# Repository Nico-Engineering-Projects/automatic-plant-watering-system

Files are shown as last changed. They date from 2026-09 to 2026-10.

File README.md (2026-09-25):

# Automatic Plant Watering System

An engineering project by Nico Gerber to develop an ESP32-based system that measures soil moisture and controls a water pump.

**Status:** In progress — breadboard assembly and development planning.

## Goal

Develop the hardware and firmware step by step, verify each stage, and document the design decisions, measurements and lessons learned.

## Current progress

- Relay and pump connected on the breadboard.
- ESP32 board selection, GPIO assignment, relay behaviour and electrical connections still need to be recorded and verified.
- Firmware development and functional testing are next.
- No watering performance or reliability results have been established yet.

## Planned development phases

- [ ] Verify ESP32 upload and Serial Monitor communication.
- [ ] Verify relay control and startup state with the pump disconnected.
- [ ] Verify a deliberately triggered short pump run with automatic shutoff.
- [ ] Measure and calibrate the soil-moisture sensor.
- [ ] Implement and test automatic watering with a soak period.
- [ ] Evaluate the results and document improvements.

## Planned software tools

- Visual Studio Code
- PlatformIO IDE
- Arduino framework for ESP32
- Git and GitHub for version history

The exact ESP32 board and GPIO configuration will be documented before the first firmware is added.

## Documentation

- [Development log](docs/development-log.md)
- Circuit diagrams, component list and test results will be added as the project progresses.
- The Word project report will be kept in `docs/`; a readable PDF can be included with major milestones.

## Project structure as the work grows

| Location | Contents |
| --- | --- |
| `README.md` | Current overview, status and setup instructions |
| `src/` | Firmware source, added when the PlatformIO project is created |
| `platformio.ini` | Verified board, framework and build configuration |
| `hardware/` | Wiring diagrams, schematics and parts list |
| `docs/` | Development log and project report |
| `results/` | Measurements and test observations |
| `images/` | Photographs of the actual project |

## Development history

Small changes are recorded as commits. Tags and releases will mark verified milestones. Each log entry should record what was actually tested and link to the relevant commit.

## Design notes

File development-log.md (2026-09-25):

# Development log

## 2026-09-25 — Initial breadboard assembly

**Goal:** begin assembling the relay and pump setup for an ESP32 watering system.

**Work recorded:** relay and pump connected on the breadboard.

**Verification:** functional and electrical checks have not yet been documented. The ESP32 model, wiring, GPIO and relay active level still need to be recorded.

**Next step:** configure the software environment and verify ESP32 communication before testing relay control.

## Format for future entries

Copy the following structure for each small stage and fill it in after doing the work:

- Date and phase: 2026/09/25 (Phase1)
- Goal: Check if the ESP32 is working and checking if relay system is working
- Hardware or wiring changes: No changes made 
- Software changes: Initialised the platform.io ide 
- Test method: Run pump for 20 seconds through the relay
- Expected result: Pump ran successfully through the relay
- Observed result: Pump ran for 20 seconds but is way to strong so would try with a smaller battery next time
- Measurements, photographs or screenshots:
- Problems and decisions: To much voltage causing pump to pump to much water at a time
- GitHub commit or release link: 
- Next step: Soil controll

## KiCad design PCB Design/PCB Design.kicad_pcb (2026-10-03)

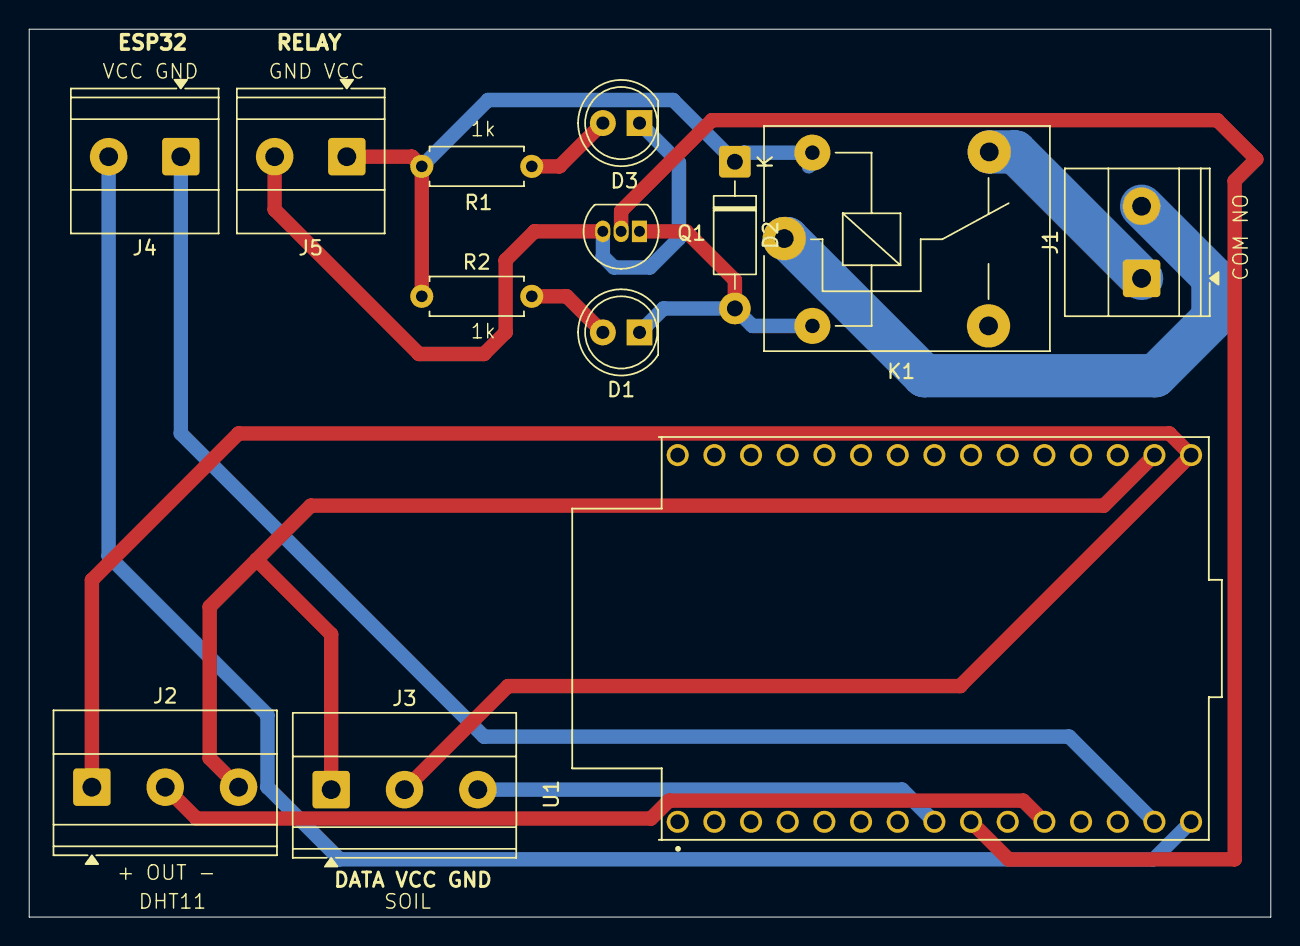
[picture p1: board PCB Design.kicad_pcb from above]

Board: 2 copper layers, 86.0 x 61.5 mm, 13 parts (0 on the bottom side), 14 nets.

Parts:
D1: GREEN; LED_D5.0mm
D2: 1N4007; D_DO-41_SOD81_P10.16mm_Horizontal
D3: RED; LED_D5.0mm
J1, J4, J5: Screw_Terminal_01x02; TerminalBlock_Phoenix_MKDS-1,5-2_1x02_P5.00mm_Horizontal
J2, J3: Screw_Terminal_01x03; TerminalBlock_Phoenix_MKDS-1,5-3-5.08_1x03_P5.08mm_Horizont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
K1: SANYOU_SRD_Form_C; Relay_SPDT_SANYOU_SRD_Series_Form_C
Q1: BC547; TO-92_Inline
R1, R2: 1k; R_Axial_DIN0207_L6.3mm_D2.5mm_P7.62mm_Horizontal
U1: DEVKIT_V1_ESP32-WROOM-32; MODULE_DEVKIT_V1_ESP32-WROOM-32

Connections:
GND: D3.1 (K), J5.2, Q1.3 (E)
unnamed: D1.2 (A), R2.2
unnamed: D1.1 (K), D2.2 (A), K1.2, Q1.1 (C)
unnamed: D2.1 (K), J5.1, K1.5, R1.1, R2.1
unnamed: D3.2 (A), R1.2
unnamed: J1.1, K1.4
unnamed: J1.2, K1.1
unnamed: J2.1, J3.2, U1.20 (3V3)
unnamed: J2.2, U1.15 (D15)
unnamed: J2.3, J3.1, U1.21 (GND)
unnamed: J3.3, U1.12 (D12)
unnamed: J4.1, U1.18 (GND)
unnamed: J4.2, U1.19 (VIN)
unnamed: Q1.2 (B), U1.13 (D13)

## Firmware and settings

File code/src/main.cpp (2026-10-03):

#include <Arduino.h>
#include <Wire.h>
#include <Adafruit_GFX.h>
#include <Adafruit_SSD1306.h>
#include <Adafruit_Sensor.h>
#include <DHT.h>


// =====================================================
// PINS
// =====================================================

#define pumpPin 13
#define tempSensorPin 15
#define moistureSensorPin 12


// =====================================================
// OLED
// =====================================================

#define SCREEN_WIDTH 128
#define SCREEN_HEIGHT 64


// =====================================================
// DHT
// =====================================================

#define DHTTYPE DHT11


// =====================================================
// SOIL CALIBRATION
// =====================================================

#define drySoil 3155
#define wetSoil 1540


// =====================================================
// WATERING SETTINGS
// =====================================================

#define DRY_LEVEL 5
#define WET_LEVEL 80


// =====================================================
// TIME CONSTANTS
// =====================================================

// Pump runs for 5 seconds
const unsigned long pumpRunTime = 5000UL;

// Allow water to soak for 5 minutes
const unsigned long soakTime = 300000UL;

// Read sensors every 2 seconds
const unsigned long checkInterval = 2000UL;

// 3 days in milliseconds
const unsigned long threedays =
    3UL * 24UL * 60UL * 60UL * 1000UL;


// =====================================================
// SENSOR VARIABLES
// =====================================================

float temp = 0;
float humidity = 0;

int soilMoisture = 0;
int rawSoilMoisture = 0;


// =====================================================
// BOOLEAN VARIABLES
// =====================================================

// Has the plant ever successfully reached 80%?
bool Watered = false;

// Is the system currently performing a watering cycle?
bool wateringMode = false;

// Is the pump physically running?
bool pumpRunning = false;


// =====================================================
// TIMER VARIABLES
// =====================================================

unsigned long pumpStartTime = 0;
unsigned long soakStartTime = 0;
unsigned long lastSensorRead = 0;

unsigned long lastWateredTime = 0;
unsigned long systemStartTime = 0;


// =====================================================
// OBJECTS
// =====================================================

Adafruit_SSD1306 display(SCREEN_WIDTH,SCREEN_HEIGHT,&Wire,-1);

DHT dht(tempSensorPin, DHTTYPE);


// =====================================================
// READ SENSORS
// =====================================================

void readSensors()
{
    // Read raw soil moisture
    rawSoilMoisture = analogRead(moistureSensorPin);

    // Convert raw reading to percentage
    soilMoisture = map(rawSoilMoisture,drySoil,wetSoil,0,100);

    // Keep moisture percentage between 0 and 100
    soilMoisture = constrain(soilMoisture,0,100);


    // Read DHT11
    temp = dht.readTemperature();
    humidity = dht.readHumidity();


    // Serial debugging
    Serial.print("Raw Soil: ");
    Serial.print(rawSoilMoisture);

    Serial.print(" | Moisture: ");
    Serial.print(soilMoisture);
    Serial.print("%");

    Serial.print(" | Temp: ");
    Serial.print(temp);

    Serial.print(" C");

    Serial.print(" | Humidity: ");
    Serial.print(humidity);

    Serial.println("%");
}


// =====================================================
// NORMAL OLED DISPLAY
// =====================================================

void displayData(const char *message)
{
    display.clearDisplay();

    display.setTextSize(1);
    display.setTextColor(SSD1306_WHITE);


    // Soil moisture
    display.setCursor(0, 0);

    display.print("Soil: ");
    display.print(soilMoisture);
    display.println("%");


    // Temperature
    display.setCursor(0, 10);

    display.print("Temp: ");
    display.print(temp, 1);
    display.println(" C");


    // Humidity
    display.setCursor(0, 20);

    display.print("Humidity: ");
    display.print(humidity, 0);
    display.println("%");


    // System status
    display.setCursor(0, 35);
    display.println(message);


    // Pump status
    display.setCursor(0, 48);

    if (pumpRunning)
    {
        display.println("Pump: ON");
    }
    else
    {
        display.println("Pump: OFF");
    }


    display.display();
}


// =====================================================
// CHECK SYSTEM DISPLAY
// =====================================================

void displayCheckSystem()
{
    display.clearDisplay();

    display.setTextColor(SSD1306_WHITE);


    display.setTextSize(2);

    display.setCursor(0, 0);
    display.println("CHECK");

    display.setCursor(0, 18);
    display.println("SYSTEM");


    display.setTextSize(1);

    display.setCursor(0, 42);
    display.println("Not watered");

    display.setCursor(0, 52);
    display.println("for 3+ days");


    display.display();
}


// =====================================================
// START PUMP
// =====================================================

void startPump()
{
    Serial.println();
    Serial.println("PUMP ON");


    // Relay is active LOW
    digitalWrite(pumpPin, LOW);


    pumpRunning = true;


    // Record when pump started
    pumpStartTime = millis();
}


// =====================================================
// STOP PUMP
// =====================================================

void stopPump()
{
    Serial.println("PUMP OFF");
    Serial.println("Starting soak period...");


    // Turn relay off
    digitalWrite(pumpPin, HIGH);


    pumpRunning = false;


    // Record beginning of soak period
    soakStartTime = millis();
}


// =====================================================
// SETUP
// =====================================================

void setup()
{
    // Start Serial Monitor
    Serial.begin(115200);


    // Pump output
    pinMode(pumpPin, OUTPUT);


    // Make sure pump starts OFF
    digitalWrite(pumpPin, HIGH);


    // Start DHT11
    dht.begin();


    // Start OLED
    if (!display.begin(
            SSD1306_SWITCHCAPVCC,
            0x3C))
    {
        Serial.println("OLED FAILED!");

        while (true)
        {
        }
    }


    // Welcome screen
    display.clearDisplay();

    display.setTextColor(SSD1306_WHITE);
    display.setTextSize(2);

    display.setCursor(0, 0);
    display.println("Welcome");

    display.display();


    delay(3000);


    // Start the 3-day timer
    systemStartTime = millis();


    // Take first sensor reading
    readSensors();
}


// =====================================================
// LOOP
// =====================================================

void loop()
{
    unsigned long currentTime = millis();


    // =================================================
    // READ SENSORS EVERY 2 SECONDS
    // =================================================

    if (currentTime - lastSensorRead >= checkInterval)
    {
        lastSensorRead = currentTime;

        readSensors();
    }


    // =================================================
    // CHECK 3-DAY WARNING
    // =================================================

    bool checkSystem = false;


    // Plant has never reached 80% since startup
    if (!Watered)
    {
        if (currentTime - systemStartTime >= threedays)
        {
            checkSystem = true;
        }
    }

    // Plant has previously been successfully watered
    else
    {
        if (currentTime - lastWateredTime >= threedays)
        {
            checkSystem = true;
        }
    }


    // =================================================
    // WAITING FOR SOIL TO REACH 5%
    // =================================================

    if (!wateringMode)
    {
        // Soil is dry enough to begin watering
        if (soilMoisture <= DRY_LEVEL)
        {
            Serial.println();
            Serial.println("========================");
            Serial.println("SOIL REACHED 5%");
            Serial.println("STARTING WATERING");
            Serial.println("========================");


            wateringMode = true;


            startPump();
        }
    }


    // =================================================
    // WATERING MODE
    // =================================================

    if (wateringMode)
    {

        // =============================================
        // PUMP CURRENTLY RUNNING
        // =============================================

        if (pumpRunning)
        {
            displayData("Watering Plant");


            // Has pump run for 1.5 seconds?
            if (currentTime - pumpStartTime >= pumpRunTime)
            {
                stopPump();
            }
        }


        // =============================================
        // PUMP OFF - SOAKING PERIOD
        // =============================================

        else
        {
            displayData("Soaking...");


            // Wait for the full soak time before deciding
            // whether more water is required
            if (currentTime - soakStartTime >= soakTime)
            {

                // Take a fresh moisture reading
                readSensors();


                Serial.println();
                Serial.print("Moisture after soaking: ");
                Serial.print(soilMoisture);
                Serial.println("%");


                // =====================================
                // TARGET REACHED
                // =====================================

                if (soilMoisture >= WET_LEVEL)
                {
                    Serial.println("========================");
                    Serial.println("SOIL REACHED 80%");
                    Serial.println("WATERING COMPLETE");
                    Serial.println("========================");


                    wateringMode = false;

                    pumpRunning = false;


                    // Make sure pump is OFF
                    digitalWrite(pumpPin, HIGH);


                    // Plant successfully watered
                    Watered = true;


                    // Reset 3-day timer
                    lastWateredTime = currentTime;


                    displayData("Watering Complete");
                }


                // =====================================
                // STILL BELOW 80%
                // =====================================

                else
                {
                    Serial.println(
                        "Below 80% - watering again"
                    );


                    startPump();
                }
            }
        }
    }


    // =================================================
    // NORMAL DISPLAY WHILE WAITING FOR NEXT 5%
    // =================================================

    if (!wateringMode)
    {
        if (checkSystem)
        {
            displayCheckSystem();
        }

        else
        {
            displayData("Waiting for 5%");
        }
    }
}

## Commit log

2026-09-25 Pump relay test and check if microcontroller is working properly.
2026-09-25 Changed the initial state of the relay to HIGH so that the pump is off when the system starts. The relay will now turn on for 10 seconds and then turn off for 20 seconds in a loop.
2026-10-01 Adding the Temp and Humidity sensor to the project library.
2026-10-01 Completed the Testing Code for temperature and humidity sensor.
2026-10-03 Starting PCB Design.
    [PCB Design.kicad_pcb, PCB Design.kicad_sch]
2026-10-03 Relay PCB design finished next is the connection for the sensors and connecting the relay to the microcontroller.
    [PCB Design.kicad_pcb, PCB Design.kicad_sch]
2026-10-03 Finished the first version of the PCB design. Added the footprint library table and removed the lock file.
    [PCB Design.kicad_pcb, PCB Design.kicad_sch]
2026-10-21 Finished with the soil calibrations and first version of the pcb design.
